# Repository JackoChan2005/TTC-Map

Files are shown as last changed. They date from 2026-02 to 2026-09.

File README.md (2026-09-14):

# TTC Map

A Toronto rail explorer and ESP32 LED display built around one transit-state API.
The web map shows Lines 1, 2, 4, 5 and 6 over OpenStreetMap, with route search,
station details, directional markers and a schematic view.

The project implements GTFS import and validation, bounded NTAS polling, estimated
train positions, a shared web/LED state model, the browser interface and firmware
for an eight-LED board revision. Contributor history is available in Git; individual
ownership and asset permissions are documented in [docs/ASSETS.md](docs/ASSETS.md).

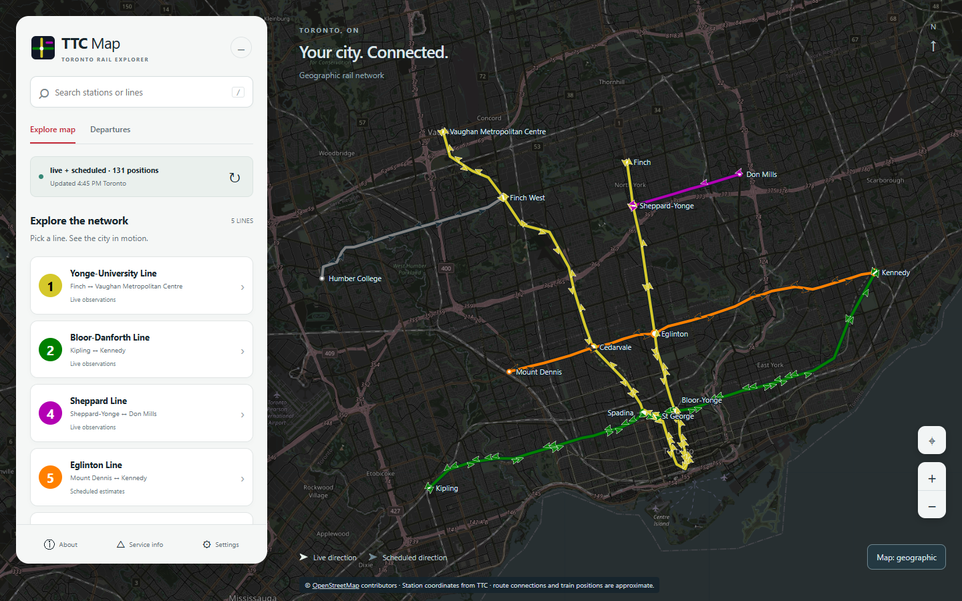
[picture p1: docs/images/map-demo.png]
TTC Map geographic explorer


The image records a real-data session on September 12, 2026; it is not a live feed.

```text
Toronto Open Data GTFS -> validated SQLite schedules/topology --+
TTC NTAS countdowns -> per-line snapshots and interpolation ----+-> map state
                                                               |-> web explorer
                                                               +-> ESP32 LED frame
```

Python/FastAPI serves the vanilla JavaScript/SVG frontend. SQLite, pandas and
HTTPX handle data; ESP-IDF/PlatformIO builds the firmware. There is no frontend
build step and no Node server.

## What the map means

- Filled arrows are NTAS-backed estimates; outlined arrows are scheduled estimates.
  Neither is GPS. Routes connect station coordinates approximately, not surveyed tracks.
- Lines 1/2/4 use NTAS when healthy. Line 5 is scheduled unless explicitly enabled
  after [coverage validation](docs/LINE_5_6.md); Line 6 is schedule-only.
- Direction follows API travel order. Unknown direction uses a neutral marker.
- Departures are scheduled, within a two-minute line-wide window capped at 200 rows.
  Service alerts, live station arrival boards and journey planning are unavailable.
- Data health does not imply normal TTC operations. Failed state requests clear
  train markers; a missing street background leaves the transit overlay usable.

## Run on Windows

Install [uv](https://docs.astral.sh/uv/getting-started/installation/), clone this
repository, then double-click `start.bat` or run it from PowerShell:

```powershell
.\start.bat
```

The launcher installs the locked dependencies and starts the server. It keeps
Python packages in `%LOCALAPPDATA%\TTC-Map\venv`, outside OneDrive. Python 3.13 is
selected by `.python-version`; uv can download it if needed. Do not repair or
reuse an old OneDrive-managed `.venv` to run this launcher.

Open <http://localhost:8000> for the map, `/search/` for timetable search, and
`/docs` or `/redoc` for the local interactive API reference. Stop with Ctrl+C.
For another port: `.\start.bat serve --port 8001`.

[Windows setup and clean-checkout verification](docs/SETUP.md) includes manual
commands, separate-checkout environments and offline rehearsal.

## macOS / Linux

Install [uv](https://docs.astral.sh/uv/getting-started/installation/), then open a
terminal in this repository and run:

```sh
./start.command
```

On macOS you can also double-click `start.command`. The launcher installs the
locked dependencies into `.venv` and starts the server. Open
<http://localhost:8000> and stop with Ctrl+C. Use
`./start.command serve --port 8001` for another port or `./start.command refresh`
for a feed check. If an extracted archive loses executable permissions, run
`bash start.command`.

Equivalent manual commands:

```sh
uv sync --locked
uv run --no-sync ttcmap serve
```

Python 3.12+ is supported by the package; the repository pins 3.13 for development.
Use one worker and a local SQLite database. Linux startup has been checked under
Ubuntu 24.04 (WSL2); macOS runtime and physical hardware validation remain separate
checks. See [setup verification](docs/SETUP.md#macos--linux).

## Commands

Run these after the platform-specific setup. On Windows, set
`$env:UV_PROJECT_ENVIRONMENT = "$env:LOCALAPPDATA\TTC-Map\venv"` first, or use
`.\start.bat refresh` for a feed check.

| Command | Purpose |
|---|---|
| `uv run --no-sync ttcmap refresh` | Check/rebuild the feed; add `--force` for a forced rebuild |
| `uv run --no-sync ttcmap build-network` | Regenerate exports from the verified cache |
| `uv run --no-sync pytest` | Backend tests |
| `uv run --no-sync ruff check src tests` | Python lint |
| `node --test tests/web/*.test.mjs` | Frontend unit tests, optional Node.js |
| `node scripts/build-schematic.mjs` | Regenerate schematic after network export |

Browser tests use a pinned optional Playwright install; see [SETUP.md](docs/SETUP.md).
There is no separate JavaScript build, type-checker or linter configured.

## API and structure

The local API reference reads `/openapi.json` and can send GET requests without
external scripts. All transit routes are below `/api/v1`:

| GET endpoint | Data |
|---|---|
| `/health`, `/gtfs/status` | Dataset and per-line source diagnostics |
| `/map-config` | Matching generation, network and schematic |
| `/network`, `/layout/{name}` | Topology or an individual layout |
| `/map-state` | Estimated positions; source and optional time selection |
| `/departures?route=1` | Scheduled departure window |
| `/led-state`, `/led-state.bin` | Board frame as JSON or packed bits |

Refresh is CLI-only. The former `POST /api/v1/gtfs/refresh` is removed so a viewer
cannot trigger an expensive rebuild. The web refresh button reloads read endpoints.

| Directory | Purpose |
|---|---|
| `src/ttcmap/` | API, GTFS pipeline, source selection and LED renderer |
| `web/` | Explorer, timetable and local API reference |
| `shared/` | Reviewed station identities and generated network/layout exports |
| `firmware/` | ESP-IDF firmware; local Wi-Fi settings are gitignored |
| `hardware/` | Integrated KiCad design and eight-LED board map |
| `tests/`, `scripts/` | Validation and schematic generation |
| `data/` | Ignored feeds, database, local validation and private asset archive |

Run from an editable repository checkout. A standalone wheel does not include the
web/shared/hardware resources and is not a supported deployment package.

## Configuration and troubleshooting

Copy `.env.example` to `.env` for optional overrides; all fields are in
`src/ttcmap/config.py`. Local paths resolve against the checkout. For OneDrive
installations that also need database isolation, configure `DATA_DIR` and `DB_PATH`
to local storage. Cloud synchronization is not multi-host database coordination.

- **Port occupied:** use another port with the launcher/CLI.
- **Transit data unavailable:** check `/api/v1/health` and refresh logs. First import,
  expired schedules or a failed upgrade can cause 503 responses.
- **Scheduled labels:** live observations may be unavailable or disabled for that line.
- **Street map unavailable:** use the schematic; OSM tiles are an external service.
- **Firmware connection:** follow [ESP32_SMOKE_TEST.md](docs/ESP32_SMOKE_TEST.md).
  The eight-LED revision does not represent a fully wired station network.

See [ARCHITECTURE.md](docs/ARCHITECTURE.md), [UI_API_AUDIT.md](docs/UI_API_AUDIT.md),
[validation results](docs/UI_VALIDATION.md) and [asset/publication status](docs/ASSETS.md).

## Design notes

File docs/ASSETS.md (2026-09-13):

# Assets and publication status

The repository has no project-wide open-source license selected by its owners.
No new reuse rights are asserted here. Contributors must confirm the intended
license and individual contribution attribution before adding a project license.

## Hardware libraries

Integrated PCB/schematic designs remain in `hardware/`. Their placed footprints
and embedded schematic symbols remain part of those designs. The separately
downloaded model files have been removed from the tracked working tree because
the included SnapMagic Design License distinguishes integrated designs from
standalone model redistribution. License notices are retained under
`hardware/My-Custom-Footprints.pretty/`.

For library editing, obtain the relevant symbols/footprints/models from the
original provider under its terms. Required part families include ESP32-DEVKIT-V1,
SN74HC595, BSS84, C0603C104K5RACTU, CL05A104KA5NNNC and JMK105BJ105KV-F.
Set KiCad's `TTC_MODEL_DIR` path variable to your local library directory, keeping
the subfolder structure shown in `hardware/sym-lib-table`. The footprint table
uses that directory as a `.pretty` library. Board viewing does not require replacing
placed footprints; missing optional models affect external library/3D operations.
Standard KiCad libraries must be installed separately.

On the original development machine, removed files were preserved under ignored
`data/private-assets/hardware/My-Custom-Footprints.pretty`. They are not licensed
for redistribution by this document. Prior Git history still contains them;
permission or a separately approved history/publication strategy remains necessary.

## UI images

The two original design-reference JPGs are preserved only in ignored local storage
pending author/provenance confirmation. The written root design document remains.
The README image is an actual TTC-Map browser capture from September 12, 2026;
its counts and source labels record that session, not current observations.

The screenshot contains OpenStreetMap imagery and visible contributor attribution.
The map uses the public OSM tile service with normal browser caching and visible
[OpenStreetMap attribution](https://www.openstreetmap.org/copyright). Transit
station/schedule data comes from Toronto Open Data, with NTAS observations where
available. Do not remove those attributions or claim that TTC endorses the project.
No downloaded font package is bundled; the UI uses available system fonts.

## Local credentials

Legacy `TTC/`, `node-api/`, `.pio`, dependency folders, environment overrides and
secrets headers are ignored. They were not deleted or published by this cleanup.
The earlier audit found a Wi-Fi literal in a local capture tree and compiled
firmware, not in the branch commits inspected. A normal branch push and a full
folder/.git archive have different exposure boundaries.

The owner must confirm whether those local files were ever shared. If exposure
occurred or is uncertain, rotate the Wi-Fi credential first and then clean shared
copies and local capture metadata. This cleanup neither rotates router credentials
nor rewrites protected tool capture refs or published Git history.

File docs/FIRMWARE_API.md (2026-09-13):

# Firmware API

The contract between the ESP32 and the server. Designed so the firmware needs no JSON parser
and a fixed-size buffer.

## The endpoint

```
GET /api/v1/led-state.bin?map=rev-a
```

| | |
|---|---|
| Response | `200 application/octet-stream`, exactly `ceil(ledCount / 8)` bytes |
| `ETag` | Content hash of the frame. Send back as `If-None-Match` to get `304` |
| `X-Led-Count` | Number of LEDs the board revision declares |
| `X-Generated-At` | ISO 8601 timestamp of the frame |
| `X-Source` | `ntas`, `schedule`, or `mixed` (sources selected per line) |

`?map=` selects a board revision; it must match `^[a-z][a-z0-9-]*$` and name a file in
`hardware/led-maps/`. Unknown names return `404`. `rev-a` is the default.

`?source=schedule` forces the schedule simulation — useful for bench testing when you want
deterministic output within the published service calendar regardless of whether NTAS is up.

## Bit layout

LED index `i` lives in **byte `i / 8`, bit `i % 8`** — LSB first within each byte.

For `rev-a` (8 LEDs, one byte), with D1 and D4 lit:

```
on          = [0, 3]
byte 0      = 0b00001001 = 0x09
             │      │└──── bit 0 → LED 0 (D1, Finch)
             │      └───── bit 3 → LED 3 (D4, St George)
             └── bit 7 → LED 7 (D8, Don Mills)
```

Reading it back out:

```c
bool led_is_on(const uint8_t *frame, int index) {
    return (frame[index / 8] >> (index % 8)) & 1;
}
```

Note this is LSB-first, while the 74HC595 shifts out MSB-first. Reverse the bits per byte
before shifting, or walk the indices with `led_is_on()` and build the shift register word
yourself — do not pass the buffer straight through.

## Suggested poll loop

1. `GET /api/v1/led-state.bin?map=rev-a` with `If-None-Match: <last etag>`.
2. `304` → nothing changed, keep the current display and skip the shift-out.
3. `200` → store the new `ETag`, latch the bytes out to the 74HC595 chain.
4. Sleep ~5s. The server refreshes realtime data every 30s, so polling faster than that only
   costs power; slower than ~30s and the board visibly lags the trains.

## Failure behaviour

| Condition | What the server does | What the firmware should do |
|---|---|---|
| NTAS feed down | Serves the schedule simulation, `X-Source: schedule` | Nothing — the frame is still valid |
| GTFS not yet built | `503` with a JSON `{message}` body | Retry with backoff; the first build takes minutes |
| Unknown `?map=` | `404` | Fix the board revision name; do not retry |
| Server unreachable | — | Hold the last frame, retry with backoff. Consider blanking after a few minutes so a frozen display is not mistaken for live data |

## Adding a board revision

Add `hardware/led-maps/<rev>.json`. No server code changes.

```json
{
  "name": "rev-b",
  "description": "Second PCB revision",
  "ledCount": 16,
  "leds": [
    { "index": 0, "designator": "D1", "station": "99992", "stationName": "Finch" }
  ]
}
```

`station` must be a station id from `shared/network.json` — `tests/test_led.py` asserts every
LED maps to a real station, so a typo fails the test suite rather than silently never lighting
up. `GET /api/v1/network` lists the ids alongside their names.

## Five-line coverage

The server includes Lines 5 and 6 in scheduled state. Line 5 can use NTAS after
coverage validation; Line 6 is scheduled only. A mixed frame has `X-Source: mixed`.
The firmware copies this header as text, so no new source enum or wire format is
required. JSON `map-state.lineSources` explains each line's source.

The existing `rev-a` byte count and LED indices do not change. Stable application
station IDs preserve the physical mapping. New-line trains at an existing mapped
interchange (for example Kennedy) can light its LED. Additional station LEDs
require a separately verified board revision; no physical assignments are guessed.

Unavailable required schedule data (including an incomplete importer migration)
returns 503 rather than a partial successful frame. On a failed browser update,
train markers are cleared; the firmware retains its existing bounded grace period.

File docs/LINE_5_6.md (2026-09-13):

# Lines 5 and 6

All five rail lines share the GTFS import, station registry, published dataset
and map-state pipeline. Public line numbers differ from feed route IDs.
Lines 5/6 have route type 0; ordinary streetcars are excluded by public identity.

Line 5 uses schedules by default. Before adding it to `NTAS_ENABLED_LINES`,
record bounded feed checks across both directions, terminals and several operating
periods. Verify payload association, changing predictions, empty queues, coverage
and cycle duration. Stop on rate limiting. A populated response alone does not
establish live provenance or reliable coverage.

The configured Line 5 gate is 90% valid platforms per direction within the poll
deadline. General live use remains unverified. Keep schedules if the gate is not
met. Line 6 is schedule-only; no live adapter is claimed.

Tests cover station identities, short turns, atomic publication, calendars,
source isolation and generation matching. See [ARCHITECTURE.md](ARCHITECTURE.md)
and [UI_API_AUDIT.md](UI_API_AUDIT.md) for current behavior.

The rev-a board retains eight mapped LEDs. New lines can activate existing
interchange LEDs; additional stations require verified wiring and a board map.

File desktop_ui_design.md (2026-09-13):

# TTC-Map Desktop UI Redesign Summary

This document outlines the design concepts, justifications, and trade-offs for a proposed "map-first" desktop interface for the TTC-Map project.

## 1. Desktop Landing View

The landing experience is designed to immediately orient the user geographically while keeping high-level system information accessible.

The original reference image is retained locally pending provenance confirmation.
See the current implementation in [README.md](README.md).

### Design Justifications
- **Map-First Geography:** Using a full-screen, dark-themed geographic base map (rather than a schematic) allows users to instantly understand where stations and live trains are located relative to actual city streets and landmarks.
- **Floating Contextual Panel:** A floating panel on the left (similar to Google Maps or Transit) keeps the map unobstructed. It provides immediate access to route search, overall system status, and quick-links to individual lines without requiring a separate page load.
- **Subtle Live Markers:** Train icons are intentionally kept small and subtle. If the map gets crowded with active trains, large icons would overlap and create visual noise.

### Trade-offs
- **Geographic vs. Schematic Clarity:** A true geographic map can make dense downtown areas (like the "U" of Line 1) feel cramped compared to a heavily distorted schematic map (like the classic TTC map). The trade-off is spatial accuracy over abstract readability.
- **Discoverability:** Floating UI panels can sometimes obscure parts of the map. While the panel is collapsible, users with smaller desktop screens might find it takes up a significant portion of their viewport compared to a traditional top navigation bar.

---

## 2. Route Details View

When a user selects a specific route (e.g., Line 1 Yonge-University), the UI shifts to a focused, progressive disclosure mode.

The original route reference is retained locally pending provenance confirmation.

### Design Justifications
- **Progressive Map Highlighting:** When a route is selected, the map zooms to fit the route's bounding box. Other subway lines are visually de-emphasized (grayed out or lowered in opacity), drawing full attention to the active route and its trains.
- **Vertical Station Timeline:** The side panel transitions from a system overview to a vertical timeline of the selected route. This makes it easy to scan the order of stations, see where trains currently are relative to the stops, and check scheduled departures when available.
- **Clear Route Branding:** The panel header takes on the official color of the selected route (Yellow for Line 1), reinforcing to the user exactly which context they are currently viewing.

### Trade-offs
- **Loss of Global Context:** By visually de-emphasizing the rest of the network, users temporarily lose system-wide situational awareness. If they are looking to plan a trip that involves a transfer to Line 2, the de-emphasized Line 2 might be slightly harder to read until they exit the route-specific view.
- **Vertical Scrolling:** Line 1 has many stations. A vertical list means users will have to scroll to see the entire route's details. An alternative would be a horizontal bottom-drawer timeline, but that would sacrifice vertical map space which is often more valuable on widescreen desktop monitors.

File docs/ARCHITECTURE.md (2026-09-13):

# Architecture

One Python service serves a rail map, scheduled departure search and ESP32 LED
frames. Node is an optional development tool for generating the schematic and
running frontend tests; it is not needed for service startup.

## Modules and contracts

| Path | Responsibility |
| --- | --- |
| `src/ttcmap/gtfs/rail_routes.py` | Select public lines 1/2/4/5/6 and validate their GTFS types |
| `src/ttcmap/gtfs/ckan.py` | Discover the ZIP resource, retain content-addressed ZIPs, verify offline cache, isolate extraction |
| `src/ttcmap/gtfs/build.py` | Validate and order rail stop times; build canonical content hashes; stage and publish tables/artifacts |
| `src/ttcmap/gtfs/network.py` | Resolve stable station identities and validate full/short-turn patterns in both directions |
| `shared/stations.json` | Reviewed application station identities, aliases and GTFS parent crosswalk |
| `src/ttcmap/gtfs/service_calendar.py` | Resolve service dates, weekday calendars, exceptions and validity |
| `src/ttcmap/gtfs/refresh.py` | Coordinate version checks, importer upgrades and publication |
| `src/ttcmap/gtfs/refresh_lock.py` | Native OS writer lock shared by CLI and server |
| `src/ttcmap/db.py` | SQLite access and a transaction-pinned Dataset context |
| `src/ttcmap/map/sources/ntas.py` | Validate and aggregate bounded HTTP polls by line and direction |
| `src/ttcmap/map/recorder.py` | Store immutable observations and carry progress floors within a generation |
| `src/ttcmap/map/sources/schedule.py` | Query dated scheduled positions and operating-service windows |
| `src/ttcmap/map/segments.py` | Generation-scoped median traversal times from explicit next-stop relationships |
| `src/ttcmap/map/interpolate.py` | Convert countdowns into estimated segment progress |
| `src/ttcmap/map/__init__.py` | Choose one source per line and assemble a consistent MapState |
| `web/js/pollMap.js` | Serialize browser polling and match state to config generation |
| `src/ttcmap/renderers/led.py` | Preserve the board's packed station-occupancy bitmask |

## Published state

`data/ttc.db` contains `SUBWAY_STOP_TIMES`, `SERVICE_DAYS`,
`SERVICE_EXCEPTIONS`, and one `active_dataset` row. The row stores topology,
layouts, generation, feed-cache identity, source version and importer revision.
Runtime never falls back to reading shared topology JSON. Shared files are
reviewable build inputs/exports; the schematic is validated before publication.

A writer builds staging tables while readers continue using the old dataset.
The final transaction swaps all tables and updates the active row and metadata.
A failed preparation or transaction leaves the previous complete dataset active.
OS locking prevents the CLI and service from colliding on staging tables. A
request pins a single SQLite read transaction and does not await HTTP while
holding it. Late polls carry their old generation and cannot be applied to a new
dataset. Segment caches are bounded and keyed by generation.

The supported deployment is one server worker on one host with local SQLite.
The OS lock also coordinates local CLI invocations. A cloud-synchronized folder
is not a supported way to share the active database across hosts.

## Source policy

`NTAS_ENABLED_LINES` defaults to `["1","2","4"]`; only 1/2/4/5 are accepted.
Line 5's 90% valid-response threshold per direction is an initial enablement gate.
Existing lines retain the provisional 50% numeric threshold, now checked per
direction. Thresholds are configuration, not provider guarantees; measure before
changing them. All platforms are included until a departure-only terminal
exclusion is verified. Line 6 is never polled by this adapter.

- `auto`: combine live and scheduled lines. `fallback` flags only an enabled
  live line needing scheduled substitution.
- `schedule`: scheduled estimates for all lines.
- `ntas`: fresh recorder data for all configured live lines, with other lines
  explicitly excluded. A missing, failed or stale enabled line returns 503.
  This mode performs no additional platform HTTP requests. No enabled lines or
  no initial snapshot also returns 503.
- Explicit `at`: use schedules; `source=ntas&at=...` returns 400. Naive timestamps
  mean Toronto local time. Prefer timestamps with explicit offsets around DST.

`lineSources` is the authoritative per-line source metadata. Top-level `source`
may be `mixed`, including when one selected line currently has no trains. A lack
of predictions during scheduled service is not proof of a suspension: the map
labels the substitute as a schedule. No public reliable Line 6 live source is
claimed. Adding GTFS-Realtime is a separate change.

## Refresh and upgrade operations

Refresh is CLI-only. The former HTTP refresh route is removed. Browser viewers
can read state and diagnostics but cannot trigger publication.

Use `uv run ttcmap refresh` to check metadata and rebuild when the feed, importer
revision or local registry/layout inputs change. `--force` rebuilds even if the
version is unchanged. The recorded metadata comes from the package used for the
download. A compatible published dataset remains usable if CKAN is offline.
An importer-only offline rebuild can use the verified cached ZIP referenced by
the active dataset. Unverified old extracted files are not an offline cache.

Existing installations need a first new-format publication; until then data
endpoints report readiness 503. Before upgrading a deployed service, back up its
SQLite database with SQLite's backup API, retain the matching application
revision, and run the rebuild before switching traffic. Restore the matching DB
and code together for rollback. Do not copy an active WAL database as a single
file or restore only JSON exports.

For new stations or layout changes:

```sh
uv run ttcmap build-network
node scripts/build-schematic.mjs
uv run ttcmap refresh --force
```

`build-network` uses the published verified ZIP and only writes shared exports.
For an explicitly extracted feed use `build-network --data-dir <directory>`.
Review `shared/stations.json` first if identity resolution fails. Unknown station
identities, unsupported patterns or missing layout coordinates reject a refresh
and leave the prior dataset active. The generator does not run at server startup.

## Validation

The test fixtures contain all five rail lines plus an excluded streetcar,
feed-specific route IDs, nonconsecutive stop sequences and dated calendars.
Tests cover mixed sources, per-line timeout isolation, snapshot generations,
calendar exceptions, midnight service, exact LED bytes, transactional failure,
reader consistency, offline upgrade, OS-lock recovery and deterministic rebuilds.
Frontend tests verify mixed labels, serialized polling and generation reloads.
Live TTC availability is not a CI dependency.

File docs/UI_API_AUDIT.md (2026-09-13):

# Frontend redesign: API capability audit

Design source: root `desktop_ui_design.md`. Original reference images are kept
locally pending provenance confirmation; they supplied visual direction, not
transit data. See `ASSETS.md`.

## Architecture and reuse

The active application is `src/ttcmap/app.py`: FastAPI routers under `/api/v1`
followed by static `web/` files. The legacy `API/` and `node-api/` directories
are not registered applications. This redesign retains vanilla ES modules,
the generation-aware map poller, network/state validation and schematic geometry.
The old SVG renderer is replaced by an interactive geographic/schematic renderer.
The two page documents share one bootstrap and stylesheet. The former separate
search client and stylesheet are removed; transit HTTP access is in `web/js/api.js`.
There are no added runtime dependencies or transit backend changes. The security
policy now permits tile images from `tile.openstreetmap.org` and an origin-only
referrer, as required by the map provider.

## UI to API mapping

All paths below are relative to `/api/v1`.

| UI feature | Endpoint and verified fields | Support and behavior |
|---|---|---|
| Overview, line cards, station/line search, transfers | `GET /map-config`: `generation`, `network.lines[]` (`id`, `number`, `routeId`, `name`, `color`, `textColor`, `stations`), `network.stations`, `network.platforms`, `layout` | Supported. Search filters published names/numbers locally; no search endpoint exists. Includes Lines 1, 2, 4, 5, 6 when published. No hardcoded transit records. |
| Geographic station map | `GET /map-config`: `network.stations[id].lat/lon`; OpenStreetMap raster tiles | Supported real street background with station coordinates projected to Web Mercator. Route connections remain approximate because the transit API has no track geometry. |
| Schematic map | `GET /map-config`: `layout` | Supported; existing schematic remains available, also used if station coordinates are missing or invalid. |
| Train markers and source labels | `GET /map-state`: `generation`, `generatedAt`, `source`, `lineSources[id].source/reason`, `trains[].line/direction/at/between/progress/stationName` | Supported as inferred positions, not GPS. Filled live markers and outlined scheduled markers; estimates can be hidden. Unknown station references are not drawn. Failed requests clear all markers. |
| Route focus and station timeline | Same network and state data | Supported. Route bounding-box fit, other lines dimmed, directional station order from the canonical direction-0 order; transfers use actual station memberships. Timeline marks trains at/approaching stations. |
| Station scheduled departures | `GET /departures?route=<number>`: `requestedAt`, `matches[].deltaSeconds`, `payload.stop_id/direction_id` joined through `network.platforms[stop_id].station/line` | Partial substitute for the design's live countdowns. Two-minute, line-wide, maximum-200-row window only; no claim of exhaustive future arrivals. Cache ages countdowns and expires past results. |
| Timetable search page | `GET /departures?route=<number>&at=<ISO8601>`: `matches[].payload`, `requestedAt` | Supported. Local datetime input is explicitly labelled with the browser time zone, sent with an offset via ISO UTC; results show Toronto/service time. Retains raw schedule record disclosure. Handles 404 as no departures, plus empty results and failures. |
| Data availability dialog | `GET /health`: `status`, `gtfs.ready`, `realtime.lines[id].source` | Supported as data diagnostics only. Never presented as good service or on-time status. |
| Pan, zoom, reset, collapse, appearance, navigation | No additional requests | Supported locally. Route/station selections use query parameters and browser history. Appearance preferences last for the session. |

Station coordinates and schematic now come from one atomic `/map-config`
response. The pixel-only equirectangular `/layout/geographic` is deliberately
not used to overlay Web Mercator tiles. The existing poller rejects
map-state/config generation mismatches. Config is reused across ten-second
state polls. Route detail departures share
one in-flight promise/cache per route for 30 seconds. Navigation tokens prevent
late search/departure responses from overwriting another selection.

## Recently introduced capabilities incorporated

Reviewed commit `5187df4` (Lines 5/6 and per-line source reliability), router
registration, every current route handler, topology generation, map-state
serialization, departure SQL/response construction, health diagnostics and the
old frontend clients. There are no extra active route handlers hidden behind
the legacy directories.

- Retains the recently added atomic `/map-config` endpoint rather than reverting
  to independently fetched network/schematic artifacts.
- Uses `/health` and the coordinates already exposed by `/map-config`.
  The refinement removes the separate geographic layout request.
- Uses expanded topology for Lines 5/6 and `map-state.lineSources`, including
  unavailable lines and scheduled fallbacks. Line 6's scheduled source is never
  called live. Line 5 remains governed by backend configuration.
- Reuses `/departures` for route details as well as the existing search page.
  The backend's current service calendar logic remains authoritative.

## Existing routes deliberately unused

| Endpoint | Reason |
|---|---|
| `GET /network` | Duplicates topology already received atomically from `/map-config`. |
| `GET /layout/geographic` | Pixel-only equirectangular layout cannot directly align to Web Mercator tiles; atomic network coordinates are the better source. |
| `GET /layout/schematic` | Matching schematic already included in `/map-config`. Other valid layout names are not assumed to exist. |
| `GET /led-state`, `GET /led-state.bin` | Hardware renderer contracts, not browser map data. |
| `GET /gtfs/status` | Subset of `/health`; no duplicate diagnostic request needed. |
| CLI `ttcmap refresh` | Publication is CLI-only; the former HTTP write route was removed. Browser refresh only reloads reads. |
| `map-state?source=ntas/schedule&at=...` variants | The main map follows backend automatic source policy. Historical time selection remains in timetable search. |

## Missing capabilities and intentional limitations

| Design feature | Missing information | Current partial support / future integration |
|---|---|---|
| Exact rail alignment / GPS positions | No served GTFS shapes or vehicle GPS coordinates | Real OSM streets and API station coordinates are supported. Routes connect stations approximately; map-state progress positions trains on those connections. Validated shapes and vehicle coordinates would improve precision. |
| Per-station live arrival countdowns/headway on cards | Public map-state serialization does not expose NTAS ETA, platform arrival queues or observation age | Two-minute scheduled departures only. A station/direction arrival endpoint should expose ETA, observation time, source and freshness. Route cards show source labels rather than fabricated minutes. |
| “All lines running normally”, disruptions, on-time status | No alerts or operational-status endpoint; health measures data readiness | Informational unavailable state plus official TTC website link. Add alerts with affected routes/stations, severity, validity and timestamps. |
| Address search and point-to-point journey planning | No geocoder, itinerary planner, walking legs or transfer-time model | Search existing stations/lines. A geocoding service and journey-planning API would be needed for those additional search modes. |
| Full station departure board | Line-wide two-minute endpoint capped at 200 rows; no pagination or longer horizon | Current timetable search preserved. Add station, direction, horizon and pagination to departure data for comprehensive boards. |
| Location centering | Browser geolocation is not connected in this iteration | No invented user location. This could be implemented as an opt-in browser permission flow using published station coordinates; it does not inherently need a transit endpoint. |
| Accounts, contact form and remote preferences pictured in reference | No authentication, profile, contact submission or preference persistence services | These decorative reference controls are not presented as working actions. About, service information and session appearance controls are functional. |

No mock/demo transit data ships in `web/`, and no static JSON is silently used
when the real API fails. Populated browser-test fixtures exist only in the
optional test runner and are explicitly identified in its code and artifacts.

## Map refinement: September 12, 2026

- Verified `map-state.trains[].direction` is 0/1, following/reversing canonical
  `line.stations`. `between` is serialized in travel order. At-station arrows
  use the next segment tangent, or incoming tangent at terminals. Missing or
  inconsistent direction produces a neutral round marker.
- Live arrows use the route colour; schedule arrows have a coloured dashed
  outline. Single-line stations have coloured rings, and transfers have segmented
  rings for connected lines. Opposing arrow glyphs sit 3.5 screen pixels to the
  travel-side of their anchor so that they remain distinguishable; the underlying
  API-derived position does not change.
- Nearby observations on the same line, direction and source share a marker;
  its tooltip reports the count. No observations or coordinates are fabricated.
- Below zoom 10.8 only interchange stations, routes and trains remain. At
  10.8–12 terminals join them; at 12–13.2 ordinary stations and eligible names
  appear. At 13.2+ labels also show line numbers. Collision detection places
  transfer labels first and uses leader lines in crowded areas. Disabling
  ordinary names never disables interchange labels. Off-screen or covered
  stations need no label.
- Marker sizes are bounded in screen pixels. Wheel zoom anchors to the pointer;
  button zoom anchors to the usable map area beside or above the panel.
- Tiles use browser image loading and normal HTTP caching for the visible
  viewport only: no proxy, prefetch, offline download or alternate transit feed.
  A tile error leaves the transit overlay working with an unavailable notice.
- Provider: [OpenStreetMap tile service](https://operations.osmfoundation.org/policies/tiles/).
  Visible attribution links to its copyright page. This is a best-effort external
  service. The URL is isolated in the map renderer; switching providers also
  requires updating CSP and attribution. Pan/zoom regression tests intercept tiles;
  one fixed-viewport integration check verifies real imagery without scanning
  the public tile service.

## Validation

See `UI_VALIDATION.md` for commands, route coverage, screenshots and actual
backend availability observed during this task.

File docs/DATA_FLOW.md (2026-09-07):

# How rail data reaches the displays

The application supports Lines 1, 2, 4, 5 Eglinton and 6 Finch West. All five
have scheduled positions. NTAS is enabled for 1/2/4 by default. Line 5 can be
enabled after coverage validation; Line 6 is scheduled only.

```text
Toronto merged GTFS ZIP                 TTC NTAS platform countdowns
         |                                         |
verified cache + isolated extraction    bounded, fair per-line polling
         |                                         |
validate schedules, calendars,          immutable per-line observations
station identities and layout           with dataset generation + time
         |                                         |
SQLite transaction publishes            reject failed, stale or
schedule + active_dataset               mismatched-generation observations
         |                                         |
         +-------------- map state ----------------+
                         |
             one selected source per line
                         |
                web map + LED bitmask
```

A refresh imports only the five public rail line numbers. Lines 5 and 6 use
GTFS route type 0; ordinary streetcars also use type 0 and are excluded. Public
line numbers and stable station IDs are independent of TTC's feed-specific IDs.
The reviewed crosswalk is `shared/stations.json`.

The published SQLite dataset contains stop times, base service calendars,
date-specific exceptions, topology and both layouts. All change in one commit.
Each map computation reads them in one transaction, so a concurrent refresh
cannot combine yesterday's topology with today's schedule. The generation hash
covers schedule/calendar content, topology, layouts and importer inputs.

The schedule source applies Toronto service dates, calendar validity and holiday
exceptions. It includes the previous service day's departures above 24:00.
Positions are departure-to-departure estimates, including dwell in the segment
span; the simulator uses local civil-clock seconds, including on DST dates.

NTAS predictions are arrival countdowns, not GPS locations or durable vehicle
identities. Polling has a shared concurrency limit and a 25-second HTTP deadline.
Completed lines remain usable when another line times out. HTTP success alone is
not sufficient: payload association and coverage are checked per direction.
A failed line loses live positions immediately; observations expire after 90
seconds. The arrival cutoff expands to cover the published segment durations.

Automatic mode chooses exactly one source for each line. `lineSources` explains
the choice and `source` is `ntas`, `schedule`, or `mixed`. A deliberately scheduled
line is not an outage. Empty predictions during scheduled operating service cause
labelled estimates, not a claim that service is actually running or suspended.
If a required schedule is unavailable, the endpoint returns 503 instead of an
apparently successful partial map.

The browser loads `/api/v1/map-config` for matching topology/layout/generation,
and reloads it when map-state generation changes. It serializes polling and
clears train markers on failed updates. The existing LED bit layout is unchanged;
new-line trains can light existing interchange LEDs, but new physical stations
need a verified board mapping. See [FIRMWARE_API.md](FIRMWARE_API.md).

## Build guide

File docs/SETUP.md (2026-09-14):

# Setup and demo rehearsal

Run from a repository checkout. Web pages, station inputs and board maps live
outside the Python package; installing a wheel alone is not supported.

## Windows

Install uv and reopen the terminal so it is on PATH. The repository selects
Python 3.13; uv installs it if necessary. Initial setup needs internet access.

```powershell
.\start.bat
```

This runs `uv sync --locked --link-mode copy` and starts the CLI using
`%LOCALAPPDATA%\TTC-Map\venv`. The environment is outside the checkout because
OneDrive can lock/reparse files in `.venv`. The launcher does not alter that old
folder. It also respects an explicit `UV_PROJECT_ENVIRONMENT` override.

Equivalent manual setup:

```powershell
$env:UV_PROJECT_ENVIRONMENT = "$env:LOCALAPPDATA\TTC-Map\venv"
uv sync --locked --link-mode copy
uv run --no-sync ttcmap serve
```

Use `start.bat serve --port 8001` for another port or `start.bat refresh` for a
feed check. `TTCMAP_NO_PAUSE=1` disables the closing prompt in scripted runs.
Do not run two checkouts against the same editable environment: assign a distinct
`UV_PROJECT_ENVIRONMENT` to each. Keep that variable set for subsequent uv test
and CLI commands. In VS Code, select the corresponding `Scripts/python.exe`.

The app defaults to loopback port 8000 and one worker. For ESP32 access on a
trusted LAN, use `serve --host 0.0.0.0` and the laptop's LAN address in the local
firmware configuration. Refresh is CLI-only; there is no HTTP write route.

The database and feed archive default to ignored `data/`. To place them outside
OneDrive too, set both `DATA_DIR` and `DB_PATH` in `.env` to a local directory and
database path before the first refresh. Never share an active SQLite database
across computers through cloud synchronization.

If the first City feed request fails, the server stays up with degraded health.
Run `start.bat refresh` when connectivity returns, then reload the site. A
successful refresh is published atomically and does not require a server restart.

## macOS / Linux

Install [uv](https://docs.astral.sh/uv/getting-started/installation/) and open a
terminal in the checkout. Initial setup needs internet; uv downloads the pinned
Python 3.13 interpreter if necessary.

```sh
./start.command
```

On macOS, double-clicking `start.command` also launches it in Terminal. The
launcher checks PATH and then `~/.local/bin/uv`, runs `uv sync --locked`, and
starts the server. It stops on installation failure and passes CLI arguments
through, for example `./start.command serve --port 8001` or
`./start.command refresh`. Use `bash start.command` if an archive extraction
did not preserve executable permissions. Stop the server with Ctrl+C.

Equivalent manual commands, run from the repository root:

```sh
uv sync --locked
uv run --no-sync ttcmap serve
```

Dependencies live in `.venv` by default. Do not reuse a Windows environment on
Linux/macOS. Set `UV_PROJECT_ENVIRONMENT` to a separate local path if the checkout
is shared across operating systems or stored in a cloud-synchronized directory;
keep it set for subsequent commands. Open <http://localhost:8000> for the map.

The default LED directory uses the tracked lowercase `hardware/led-maps` path.
Linux validation uses a fresh checkout on Ubuntu 24.04 under WSL2, on its
case-sensitive filesystem, with Python 3.13.15. macOS runtime validation has not
been performed; the launcher uses Bash syntax compatible with macOS's bundled
Bash. Neither check validates physical hardware.

Startup verification on September 13, 2026 passed locked dependency installation,
113 backend tests and Ruff. The checkout path contained spaces, and the launcher
was also invoked from another directory. HTTP checks returned 200 for `/`,
`/search/`, `/docs`, `/redoc`, `/openapi.json` and `/api/v1/health`. With an empty
database and intentionally unreachable feed service, health reported degraded
and `/api/v1/map-state` returned 503 as expected. Ctrl+C completed application
shutdown. Launcher regression tests cover default startup, argument quoting,
custom ports, installation failure and command exit-code propagation. This did
not validate a live GTFS download or NTAS service availability.

## Offline rehearsal

1. While online, run `uv run --no-sync ttcmap refresh` and check
   `/api/v1/health`: the published schedule must be ready for the presentation date.
2. Stop the server. Set `MAP_SOURCE=schedule` in `.env` or the shell, then restart.
   Markers should be outlined and labelled scheduled. This uses real published
   schedules, not a synthetic feed.
3. Disconnect external access and reload `/`, `/search/`, `/docs` and `/redoc`.
   Use the schematic if street tiles are unavailable. The API reference needs
   no external JavaScript or CSS. Try a scheduled departure search.
4. Restore automatic mode for a live demonstration. Lines 5/6 remain scheduled
   by default. Never describe schedule fallback as proof of operational service.

A compatible existing publication survives a metadata outage. An offline importer
upgrade can use the checksum-verified ZIP recorded in the dataset. Neither path
makes expired calendars valid. With no usable publication or cache, transit APIs
return unavailable states; a fresh offline clone is intentionally not populated.
For a backup of a running database use SQLite's backup API, not a raw WAL file copy.

## Tests

After the platform setup above, from the repository root:

```sh
uv run --no-sync pytest
uv run --no-sync ruff check src tests
node --test tests/web/*.test.mjs
git diff --check
```

Node is optional for service startup. Browser tests require the separately pinned
Playwright package. Install it from its own directory:

```sh
cd tests/web
npm ci
npx playwright install chromium
cd ../..
node tests/web/browser-smoke.mjs
node tests/web/map-lod-smoke.mjs
node tests/web/docs-smoke.mjs
```

On PowerShell use `npm.cmd` and `npx.cmd` if script execution policy blocks their
PowerShell wrappers. Set `TTCMAP_URL` for another server port. `CHROME_PATH` can
point to an already-installed compatible Chrome instead of downloading Chromium;
there is no machine-specific executable default. `PLAYWRIGHT_MODULE` is an optional
absolute module override for existing tool installations.

The runners resolve fixtures from the repository root and write ignored results
under `data/ui-validation`. Pan/zoom tests intercept tile images. The separate
`basemap-live.mjs` is a manual, fixed-viewport integration check; do not use public
OSM tiles for repeated automated pan/zoom scans. Transit fixtures are explicitly
test-only and never become application fallback data.

Python TestClient's `httpx2` dependency is locked in the development group to avoid
the deprecated HTTPX compatibility path. Runtime feed requests continue using HTTPX.
There is no JS build/type-check/lint command configured.

If pytest reports `Access is denied` for `%TEMP%\pytest-of-<user>` on Windows,
point `TEMP` and `TMP` at an ignored writable directory for that terminal:

```powershell
New-Item -ItemType Directory -Force data\test-temp | Out-Null
$env:TEMP = "$PWD\data\test-temp"
$env:TMP = $env:TEMP
uv run --no-sync pytest
```

## Hardware and sharing

Follow [ESP32_SMOKE_TEST.md](ESP32_SMOKE_TEST.md) for firmware. A successful compile
does not verify GPIO wiring or a physical display. Optional CAD libraries are
described in [ASSETS.md](ASSETS.md).

Share a reviewed checkout or archive of the intended commit, excluding `.git`,
local captures, `data/`, `.env`, secrets headers and build directories. An archive
of an old commit still contains its old files. Asset removals in this revision do
not erase them from prior history. Resolve the remaining ownership/history questions
in [ASSETS.md](ASSETS.md) before publishing the repository itself.

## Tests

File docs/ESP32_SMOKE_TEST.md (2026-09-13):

# ESP32 smoke test

1. Copy `firmware/include/secrets.h.example` to `firmware/include/secrets.h` and set the
   Wi-Fi profiles plus the laptop's LAN URL. The local file is ignored by Git.
2. From the repository root, start the API on the laptop with
   `uv run ttcmap serve --host 0.0.0.0`. Port `8000` is the default. The server
   must be reachable from the ESP32; do not put `localhost` in `TTC_FRAME_URL`.
3. Check the binary contract from another device on the same network:

   ```text
   GET /api/v1/led-state.bin?map=rev-a
   ```

   It returns packed bytes with `ETag`, `X-Led-Count`, `X-Generated-At`, and
   `X-Source` headers. Repeating the request with `If-None-Match` should return
   `304` when the frame is unchanged.
4. Build with `pio run --project-dir firmware`, then flash the `firmware`
   PlatformIO project and open the monitor at 115200 baud. The
   expected sequence is Wi-Fi association, an `RX frame` line, decoded LED
   indices, a 74HC595 latch line, then periodic `HTTP 304` lines.

Never commit `firmware/include/secrets.h`; it contains local credentials and the
LAN address.

The project uses a 2 MB flash layout to match the checked-in SDK configuration;
this does not measure the chip's physical capacity. Keep that setting aligned when
regenerating sdkconfig. The current rev-a consumer drives eight LEDs through two
four-bit register groups. Compilation verifies neither wiring nor Wi-Fi operation.

On Windows, PlatformIO may be installed by its editor extension without being on
PATH. Its usual command is `%USERPROFILE%\.platformio\penv\Scripts\platformio.exe`;
use the PlatformIO terminal if it is installed elsewhere.

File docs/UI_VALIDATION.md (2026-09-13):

# Validation

Latest cleanup validation: September 13, 2026, Windows, Python 3.13.15 and Node 22.
See [SETUP.md](SETUP.md) for reproducible setup and [ASSETS.md](ASSETS.md) for
the remaining ownership decisions.

## Automated checks

| Check | Result |
|---|---|
| `uv sync --locked --link-mode copy` in a fresh environment | Passed; editable project built from the lockfile |
| `python -m pytest -p no:cacheprovider --basetemp=data/review/pytest-readiness-20260913` | 108 passed without warnings |
| `python -m ruff check src tests` | Passed |
| `node --test tests/web/*.test.mjs` | 41 passed; six obsolete renderer tests were removed |
| `node tests/web/browser-smoke.mjs` | Passed on the updated app and fresh source clone |
| `node tests/web/map-lod-smoke.mjs` | Passed transfer labels, collisions, zoom detail, marker bounds and tile failure |
| `node tests/web/docs-smoke.mjs` | Passed local assets, all reference URLs, GET execution, mobile and schema failure states |
| PlatformIO build with example configuration | Passed; 896,661 bytes flash and 34,528 bytes RAM |

Python checks used a separate environment under
`%LOCALAPPDATA%/TTC-Map/readiness-venv`. Browser checks used locked Playwright
1.63.0 and installed Chrome through `CHROME_PATH`, with `TTCMAP_URL` set to the
test server. See SETUP for the default Chromium installation. Pan and zoom tests
intercept tiles; no repeated real-tile scan was performed.

## Clean-clone launch

The uncommitted working source was copied into an isolated snapshot repository,
committed there only, and cloned with `git clone --no-local` into an ignored
validation directory. This tests the changed source, not the previous remote
branch. No original Git metadata, local captures, private assets, environment,
cache or database was copied. The temporary commit did not change this branch.

The final clean-clone rehearsal used `start.bat serve --host 127.0.0.1 --port
8010` and a new environment at
`%LOCALAPPDATA%/TTC-Map/boot-verification-20260913-2`. It used the installed uv
executable and package cache; this was not a new operating-system installation.
The first startup feed request failed transiently while City metadata remained
reachable. The server stayed available with degraded health. The documented
`start.bat refresh` retry then published 109 stations and valid schedules for all
five lines without restarting the server. No transit fixture populated the
application data. The server health became `ok`; its process-local `lastRefresh`
field retained the earlier startup error even though the published dataset and
per-line health fields reflected the successful external refresh.

The clean-clone Python run initially encountered a pre-existing Windows ACL error
under `%TEMP%\pytest-of-zhouj`. Pointing `TEMP` and `TMP` at the checkout's ignored
`data/test-temp` directory produced the recorded 108-pass result. SETUP documents
that workaround.

With feed origins deliberately pointed to a refusing local port, the prepared
dataset still returned HTTP 200 with scheduled positions. An empty data directory
returned degraded health and map-state 503. These checks simulate external-service
failure; they do not claim the machine was physically disconnected. The API
reference rendered while all external browser requests were blocked.

## Browser coverage

Directly loaded `/`, `/index.html`, `/search`, `/search/`, `/search/index.html`,
`/map`, `/map/`, and route/station selections for Lines 1/2/4/5/6. Real timetable
queries for all five lines returned 200. The local API reference rendered at
`/docs`, `/redoc`, `/api/` and `/api/index.html`; `/openapi.json` remains available.

Checked navigation and back, line/station search, direction selection, scheduled
countdowns, dialogs, settings, zoom, fit, geographic/schematic mode and panel
controls. Tested 1440×900, 768×1024, 390×844 and 320×640. Browser fixtures cover
empty data, missing fields/coordinates, departure 404/503, state failure clearing
markers and tile outages. All eight interchange labels remain at wide zoom. No
unexpected console, runtime or network errors occurred in successful runs.

The final browser run used the clean-clone server and current City data. It
reported 109 stations, 119 positions at capture time, live NTAS observations for
Lines 1/2/4, scheduled estimates for Lines 5/6, and successful departure queries
for all five lines. A visible browser check confirmed the geographic basemap,
coloured routes, directional train markers, departure results and both API
reference URLs. Browser warning/error logs were empty.

The rider UI calls `/api/v1/map-config`, `/api/v1/map-state`,
`/api/v1/departures` and `/api/v1/health`. The reference can issue existing GET
endpoints. Tests confirm the removed HTTP refresh route is absent from OpenAPI and
rejects POST.

## Scope

The September 12 map integration check loaded 35 real OSM tiles in one fixed
viewport with attribution and referrers. The README screenshot comes from that
session; current counts naturally differ. It is not a data fixture.

There is no JavaScript build, type checker or linter configured. A standalone
wheel is unsupported because repository resources are required. Linux, macOS,
physical GPIO and Wi-Fi connection behavior were not tested.

The successful firmware build initially reported a 4 MB PlatformIO board default
against the checked-in 2 MB SDK layout. `board_upload.flash_size = 2MB` now aligns
that metadata. PlatformIO's builder source confirms this setting controls the
comparison. A repeat build after the one-line correction could not acquire the
user-level PlatformIO lock from the sandbox; the full compile immediately before
the correction passed. Re-run the documented build outside the sandbox before
flashing hardware.

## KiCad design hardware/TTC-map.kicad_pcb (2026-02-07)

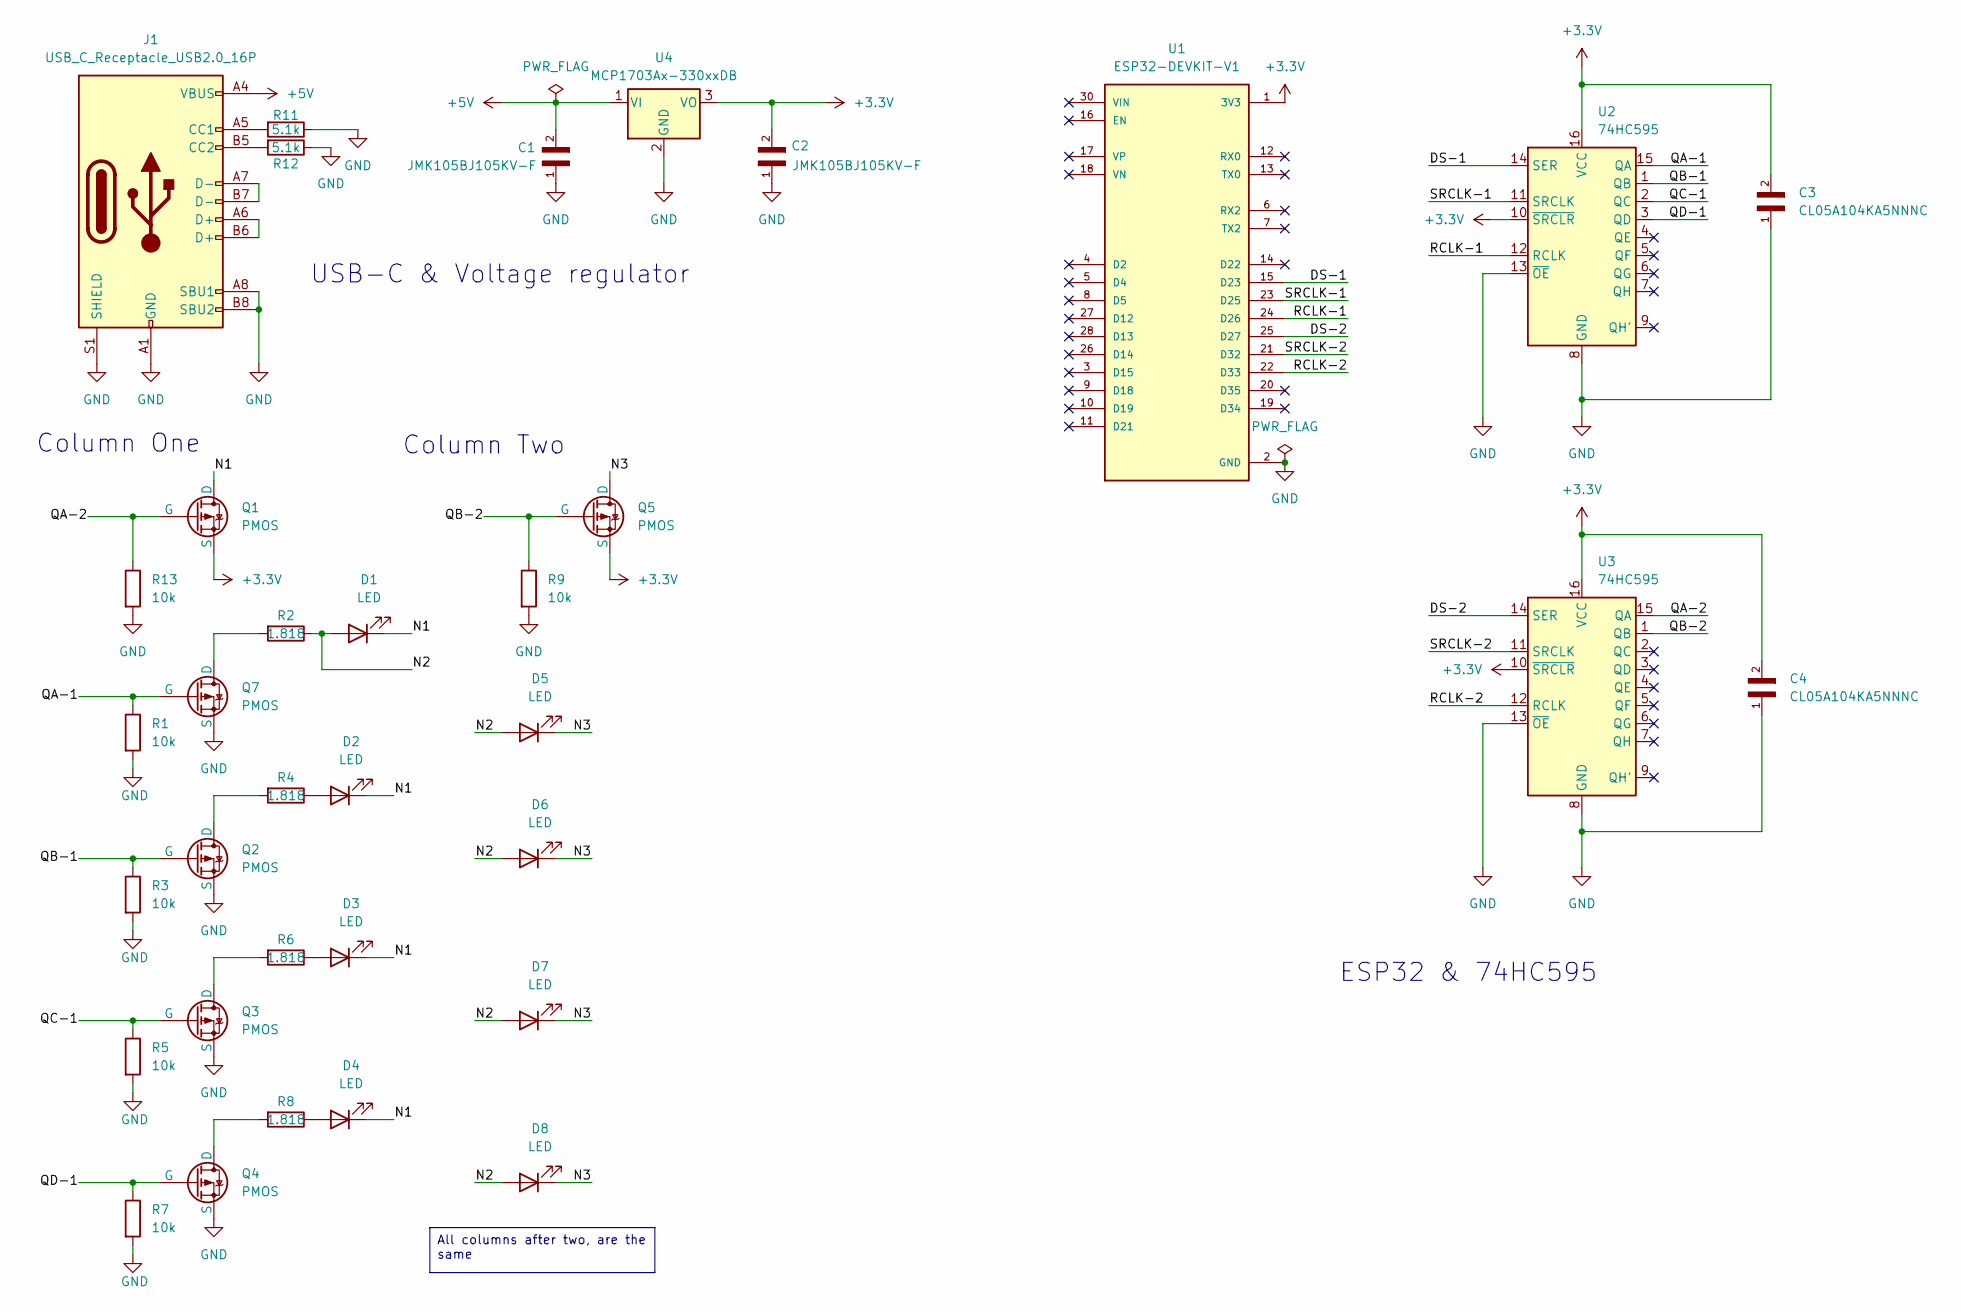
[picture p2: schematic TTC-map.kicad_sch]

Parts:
C1, C2: JMK105BJ105KV-F; CAPC1005X55N
C3, C4: CL05A104KA5NNNC; CAPC1005X55N
D1, D2, D3, D4, D5, D6, D7, D8: LED; LED_D3.0mm
J1: USB_C_Receptacle_USB2.0_16P; USB_C_Receptacle_GCT_USB4105-xx-A_16P_TopMnt_Horizontal
Q1, Q2, Q3, Q4, Q5, Q7: PMOS; SOT95P240X120-3N
R1, R3, R5, R7, R9, R13: 10k; R_0805_2012Metric
R2, R4, R6, R8: 1.818; R_0805_2012Metric
R11, R12: 5.1k; R_0805_2012Metric
U1: ESP32-DEVKIT-V1; MODULE_ESP32_DEVKIT_V1; PARTREV N/A
U2, U3: 74HC595; SOIC127P600X175-16N
U4: MCP1703Ax-330xxDB; SOT-223-3_TabPin2

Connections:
+3.3V: C2.2, C3.2, C4.2, Q1.3 (S), Q5.3 (S), U1.1 (3V3), U2.10 (~SRCLR), U2.16 (VCC), U3.10 (~SRCLR), U3.16 (VCC), U4.3 (VO)
+5V: C1.2, J1.A4 (VBUS), J1.A9 (VBUS), J1.B4 (VBUS), J1.B9 (VBUS), U4.1 (VI)
/DS-1: U1.15 (D23), U2.14 (SER)
/DS-2: U1.25 (D27), U3.14 (SER)
/N1: D1.1 (K), D2.1 (K), D3.1 (K), D4.1 (K), Q1.1 (D)
/N2: D1.2 (A), D5.2 (A), D6.2 (A), D7.2 (A), D8.2 (A), R2.1
/N3: D5.1 (K), D6.1 (K), D7.1 (K), D8.1 (K), Q5.1 (D)
/QA-1: Q7.2 (G), R1.1, U2.15 (QA)
/QA-2: Q1.2 (G), R13.1, U3.15 (QA)
/QB-1: Q2.2 (G), R3.1, U2.1 (QB)
/QB-2: Q5.2 (G), R9.1, U3.1 (QB)
/QC-1: Q3.2 (G), R5.1, U2.2 (QC)
/QD-1: Q4.2 (G), R7.1, U2.3 (QD)
/RCLK-1: U1.24 (D26), U2.12 (RCLK)
/RCLK-2: U1.22 (D33), U3.12 (RCLK)
/SRCLK-1: U1.23 (D25), U2.11 (SRCLK)
/SRCLK-2: U1.21 (D32), U3.11 (SRCLK)
GND: C1.1, C2.1, C3.1, C4.1, J1.A1 (GND), J1.A8 (SBU1), J1.A12 (GND), J1.B1 (GND), J1.B8 (SBU2), J1.B12 (GND), J1.S1 (SHIELD), Q2.3 (S), Q3.3 (S), Q4.3 (S), Q7.3 (S), R1.2, R3.2, R5.2, R7.2, R9.2, R11.1, R12.1, R13.2, U1.2 (GND), U1.29 (GND), U2.8 (GND), U2.13 (~OE), U3.8 (GND), U3.13 (~OE), U4.2 (GND)
unnamed: D2.2 (A), R4.1
unnamed: D3.2 (A), R6.1
unnamed: D4.2 (A), R8.1
unnamed: J1.A5 (CC1), R11.2
unnamed: J1.B5 (CC2), R12.2
unnamed: J1.A6 (D+), J1.B6 (D+)
unnamed: J1.A7 (D-), J1.B7 (D-)
unnamed: Q2.1 (D), R4.2
unnamed: Q3.1 (D), R6.2
unnamed: Q4.1 (D), R8.2
unnamed: Q7.1 (D), R2.2

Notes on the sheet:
USB-C & Voltage regulator
Column Two
ESP32 & 74HC595
Column One
All columns after two, are the same

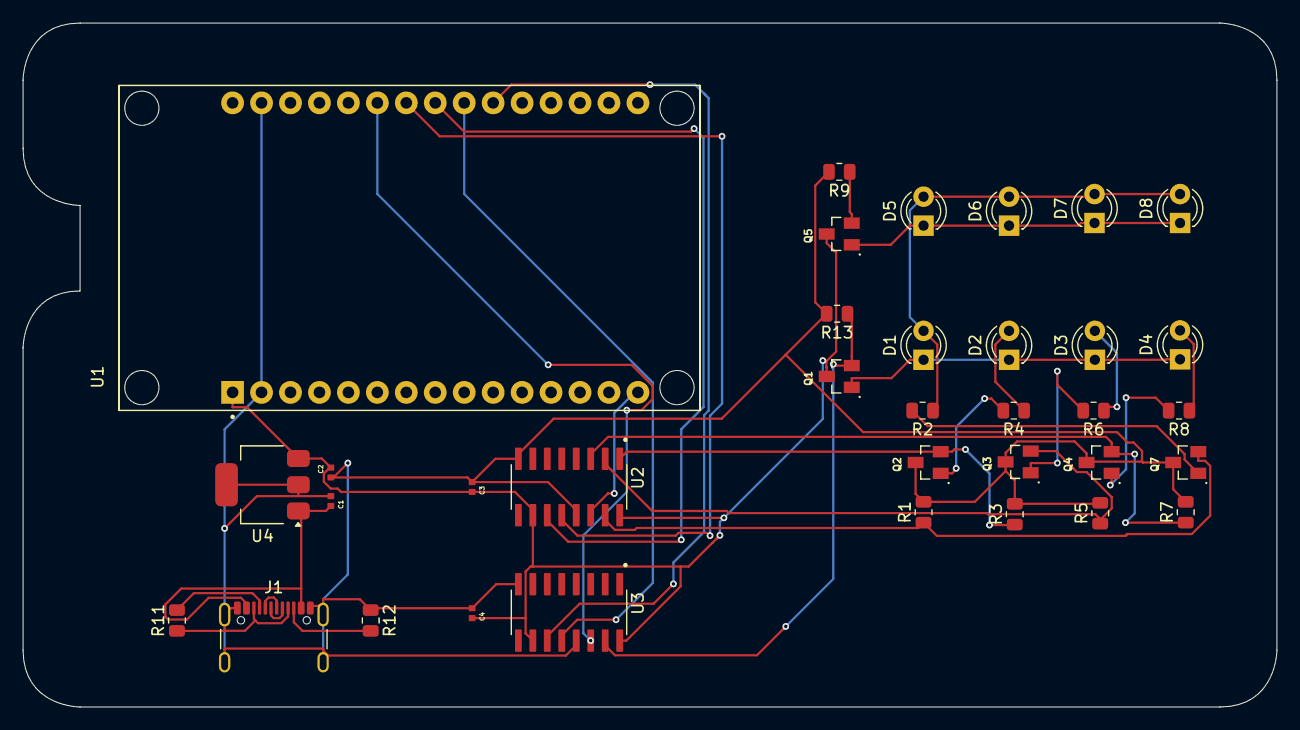
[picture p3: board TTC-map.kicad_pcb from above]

Board: 2 copper layers, 110.0 x 60.0 mm, 35 parts (0 on the bottom side), 29 nets.

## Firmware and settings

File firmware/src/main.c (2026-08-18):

#include <errno.h>
#include <inttypes.h>
#include <stdbool.h>
#include <stdint.h>
#include <stdio.h>
#include <stdlib.h>
#include <string.h>
#include <strings.h>

#include "driver/gpio.h"
#include "esp_event.h"
#include "esp_http_client.h"
#include "esp_log.h"
#include "esp_netif.h"
#include "esp_system.h"
#include "esp_wifi.h"
#include "freertos/FreeRTOS.h"
#include "freertos/event_groups.h"
#include "freertos/task.h"
#include "nvs_flash.h"

#include "board_config.h"
#include "secrets.h"

#ifndef TTC_POLL_INTERVAL_MS
#define TTC_POLL_INTERVAL_MS 5000U
#endif

#ifndef TTC_STALE_AFTER_MS
#define TTC_STALE_AFTER_MS (3U * 60U * 1000U)
#endif

#ifndef TTC_HTTP_TIMEOUT_MS
#define TTC_HTTP_TIMEOUT_MS 8000U
#endif

#ifndef TTC_VERBOSE_LED_LOG
#define TTC_VERBOSE_LED_LOG 0
#endif

#ifndef TTC_ENABLE_SHIFT_OUTPUT
#define TTC_ENABLE_SHIFT_OUTPUT 1
#endif

#ifndef TTC_WIFI_CONNECT_TIMEOUT_MS
#define TTC_WIFI_CONNECT_TIMEOUT_MS 12000U
#endif

#ifndef TTC_WIFI_RETRY_BASE_MS
#define TTC_WIFI_RETRY_BASE_MS 2000U
#endif

#ifndef TTC_WIFI_RETRY_MAX_MS
#define TTC_WIFI_RETRY_MAX_MS 30000U
#endif

#define WIFI_CONNECTED_BIT BIT0
#define WIFI_DISCONNECTED_BIT BIT1

#define TTC_MAX_ETAG_LEN 80U
#define TTC_MAX_HEADER_LEN 96U
#define TTC_MAX_SOURCE_LEN 24U
#define TTC_MAX_FRAME_BYTES ((TTC_BOARD_LED_CAPACITY + 7U) / 8U)

#if defined(TTC_WIFI_FALLBACK_SSID) != defined(TTC_WIFI_FALLBACK_PASSWORD)
#error "Define both TTC_WIFI_FALLBACK_SSID and TTC_WIFI_FALLBACK_PASSWORD"
#endif

typedef struct {
    const char *ssid;
    const char *password;
} wifi_profile_t;

static const wifi_profile_t s_wifi_profiles[] = {
    {TTC_WIFI_SSID, TTC_WIFI_PASSWORD},
#ifdef TTC_WIFI_FALLBACK_SSID
    {TTC_WIFI_FALLBACK_SSID, TTC_WIFI_FALLBACK_PASSWORD},
#endif
};

static const char *TAG = "ttc-esp32";
static EventGroupHandle_t s_wifi_events;

typedef struct {
    uint8_t body[TTC_MAX_FRAME_BYTES];
    size_t body_len;
    bool body_overflow;
    char content_type[TTC_MAX_HEADER_LEN];
    char etag[TTC_MAX_ETAG_LEN];
    char led_count_text[16];
    char generated_at[TTC_MAX_HEADER_LEN];
    char source[TTC_MAX_SOURCE_LEN];
} http_response_t;

typedef struct {
    uint8_t bytes[TTC_MAX_FRAME_BYTES];
    size_t byte_len;
    uint16_t led_count;
    uint32_t crc32;
    TickType_t last_contact;
    char etag[TTC_MAX_ETAG_LEN];
    char generated_at[TTC_MAX_HEADER_LEN];
    char source[TTC_MAX_SOURCE_LEN];
    bool valid;
    bool stale;
} led_frame_t;

static led_frame_t s_frame;

static void copy_header(char *destination, size_t destination_size, const char *value)
{
    if (!destination || destination_size == 0) {
        return;
    }
    if (!value) {
        destination[0] = '\0';
        return;
    }
    snprintf(destination, destination_size, "%s", value);
}

static esp_err_t http_event_handler(esp_http_client_event_t *event)
{
    http_response_t *response = event->user_data;
    if (!response) {
        return ESP_OK;
    }

    switch (event->event_id) {
    case HTTP_EVENT_ON_HEADER:
        if (!event->header_key || !event->header_value) {
            break;
        }
        if (strcasecmp(event->header_key, "Content-Type") == 0) {
            copy_header(response->content_type, sizeof(response->content_type), event->header_value);
        } else if (strcasecmp(event->header_key, "ETag") == 0) {
            copy_header(response->etag, sizeof(response->etag), event->header_value);
        } else if (strcasecmp(event->header_key, "X-Led-Count") == 0) {
            copy_header(response->led_count_text, sizeof(response->led_count_text), event->header_value);
        } else if (strcasecmp(event->header_key, "X-Generated-At") == 0) {
            copy_header(response->generated_at, sizeof(response->generated_at), event->header_value);
        } else if (strcasecmp(event->header_key, "X-Source") == 0) {
            copy_header(response->source, sizeof(response->source), event->header_value);
        }
        break;

    case HTTP_EVENT_ON_DATA:
        if (event->data_len <= 0) {
            break;
        }
        if (response->body_len + (size_t)event->data_len > sizeof(response->body)) {
            response->body_overflow = true;
            break;
        }
        memcpy(response->body + response->body_len, event->data, (size_t)event->data_len);
        response->body_len += (size_t)event->data_len;
        break;

    default:
        break;
    }
    return ESP_OK;
}

static uint32_t crc32_frame(const uint8_t *data, size_t length)
{
    uint32_t crc = UINT32_MAX;
    for (size_t i = 0; i < length; ++i) {
        crc ^= data[i];
        for (unsigned bit = 0; bit < 8; ++bit) {
            crc = (crc >> 1) ^ (0xEDB88320U & (-(int32_t)(crc & 1U)));
        }
    }
    return ~crc;
}

static bool parse_led_count(const char *text, uint16_t *count)
{
    if (!text || !*text || !count) {
        return false;
    }
    errno = 0;
    char *end = NULL;
    long parsed = strtol(text, &end, 10);
    if (errno != 0 || end == text || *end != '\0' || parsed <= 0 ||
        parsed > TTC_BOARD_LED_CAPACITY) {
        return false;
    }
    *count = (uint16_t)parsed;
    return true;
}

static bool response_has_required_headers(const http_response_t *response, uint16_t *led_count)
{
    if (!response || response->body_overflow || !response->content_type[0] ||
        !response->etag[0] || !response->generated_at[0] || !response->source[0]) {
        return false;
    }
    if (strncasecmp(response->content_type, "application/octet-stream", 24) != 0) {
        return false;
    }
    return parse_led_count(response->led_count_text, led_count);
}

static bool response_padding_is_zero(const uint8_t *body, size_t body_len, uint16_t led_count)
{
    if (!body || body_len == 0 || (led_count % 8U) == 0) {
        return true;
    }
    unsigned valid_bits = led_count % 8U;
    uint8_t valid_mask = (uint8_t)((1U << valid_bits) - 1U);
    return (body[body_len - 1U] & (uint8_t)~valid_mask) == 0;
}

static bool led_is_on(const uint8_t *body, size_t body_len, uint16_t index)
{
    if (!body || (size_t)(index / 8U) >= body_len) {
        return false;
    }
    return (body[index / 8U] & (uint8_t)(1U << (index % 8U))) != 0;
}

static size_t append_lit_indices(char *output, size_t output_size, const uint8_t *body,
                                 size_t body_len, uint16_t led_count)
{
    if (!output || output_size == 0) {
        return 0;
    }
    size_t used = 0;
    output[0] = '\0';
    for (uint16_t index = 0; index < led_count; ++index) {
        if (!led_is_on(body, body_len, index)) {
            continue;
        }
        int written = snprintf(output + used, output_size - used, "%s%u",
                               used ? "," : "", (unsigned)index);
        if (written < 0 || (size_t)written >= output_size - used) {
            if (output_size >= 4U) {
                snprintf(output + output_size - 4U, 4U, "...");
            }
            break;
        }
        used += (size_t)written;
    }
    if (used == 0) {
        snprintf(output, output_size, "none");
    }
    return used;
}

static void print_frame_diagnostics(const led_frame_t *frame)
{
    char hex[(TTC_MAX_FRAME_BYTES * 2U) + 1U] = {0};
    char lit_indices[(TTC_BOARD_LED_CAPACITY * 4U) + 8U] = {0};
    size_t hex_used = 0;
    for (size_t i = 0; i < frame->byte_len && hex_used + 2U < sizeof(hex); ++i) {
        hex_used += (size_t)snprintf(hex + hex_used, sizeof(hex) - hex_used, "%02x", frame->bytes[i]);
    }
    append_lit_indices(lit_indices, sizeof(lit_indices), frame->bytes, frame->byte_len,
                       frame->led_count);
    ESP_LOGI(TAG, "RX frame: hex=%s bytes=%u leds=%u source=%s crc32=%08" PRIx32,
             hex, (unsigned)frame->byte_len, (unsigned)frame->led_count, frame->source,
             frame->crc32);
    ESP_LOGI(TAG, "Decoded lit indices: %s", lit_indices);

#if TTC_VERBOSE_LED_LOG
    for (uint16_t index = 0; index < frame->led_count; ++index) {
        ESP_LOGI(TAG, "  led[%u]=%s", (unsigned)index,
                 led_is_on(frame->bytes, frame->byte_len, index) ? "ON" : "off");
    }
#endif
}

static void shift_register_write(gpio_num_t data_pin, gpio_num_t clock_pin, gpio_num_t latch_pin,
                                 uint8_t value)
{
    gpio_set_level(latch_pin, 0);
    for (int bit = 7; bit >= 0; --bit) {
        gpio_set_level(clock_pin, 0);
        gpio_set_level(data_pin, (value >> bit) & 1U);
        gpio_set_level(clock_pin, 1);
    }
    gpio_set_level(clock_pin, 0);
    gpio_set_level(latch_pin, 1);
    gpio_set_level(latch_pin, 0);
}

static void shift_output_init(void)
{
#if TTC_ENABLE_SHIFT_OUTPUT
    const gpio_config_t output_config = {
        .pin_bit_mask = (1ULL << TTC_U2_SER) | (1ULL << TTC_U2_SRCLK) | (1ULL << TTC_U2_RCLK) |
                        (1ULL << TTC_U3_SER) | (1ULL << TTC_U3_SRCLK) | (1ULL << TTC_U3_RCLK),
        .mode = GPIO_MODE_OUTPUT,
        .pull_up_en = GPIO_PULLUP_DISABLE,
        .pull_down_en = GPIO_PULLDOWN_DISABLE,
        .intr_type = GPIO_INTR_DISABLE,
    };
    ESP_ERROR_CHECK(gpio_config(&output_config));
    shift_register_write(TTC_U2_SER, TTC_U2_SRCLK, TTC_U2_RCLK, 0);
    shift_register_write(TTC_U3_SER, TTC_U3_SRCLK, TTC_U3_RCLK, 0);
#else
    ESP_LOGI(TAG, "74HC595 output disabled by TTC_ENABLE_SHIFT_OUTPUT");
#endif
}

static void shift_frame_to_board(const led_frame_t *frame)
{
#if TTC_ENABLE_SHIFT_OUTPUT
    uint8_t u2 = frame->byte_len > 0 ? frame->bytes[0] & 0x0FU : 0;
    uint8_t u3 = frame->byte_len > 0 ? (frame->bytes[0] >> 4) & 0x0FU : 0;
    shift_register_write(TTC_U2_SER, TTC_U2_SRCLK, TTC_U2_RCLK, u2);
    shift_register_write(TTC_U3_SER, TTC_U3_SRCLK, TTC_U3_RCLK, u3);
    ESP_LOGI(TAG, "74HC595 latch complete: U2=0x%02x U3=0x%02x", u2, u3);
#else
    (void)frame;
#endif
}

static void wifi_event_handler(void *arg, esp_event_base_t event_base, int32_t event_id,
                               void *event_data)
{
    (void)arg;
    if (event_base == WIFI_EVENT && event_id == WIFI_EVENT_STA_DISCONNECTED) {
        const wifi_event_sta_disconnected_t *disconnected = event_data;
        xEventGroupClearBits(s_wifi_events, WIFI_CONNECTED_BIT);
        xEventGroupSetBits(s_wifi_events, WIFI_DISCONNECTED_BIT);
        ESP_LOGW(TAG, "Wi-Fi disconnected (reason=%d)",
                 disconnected ? (int)disconnected->reason : -1);
    } else if (event_base == IP_EVENT && event_id == IP_EVENT_STA_GOT_IP) {
        xEventGroupClearBits(s_wifi_events, WIFI_DISCONNECTED_BIT);
        xEventGroupSetBits(s_wifi_events, WIFI_CONNECTED_BIT);
        ESP_LOGI(TAG, "Wi-Fi connected; local address acquired");
    }
}

static void wifi_init(void)
{
    s_wifi_events = xEventGroupCreate();
    if (!s_wifi_events) {
        ESP_LOGE(TAG, "Unable to allocate Wi-Fi event group");
        abort();
    }
    ESP_ERROR_CHECK(esp_netif_init());
    ESP_ERROR_CHECK(esp_event_loop_create_default());
    ESP_ERROR_CHECK(esp_netif_create_default_wifi_sta() ? ESP_OK : ESP_FAIL);

    wifi_init_config_t config = WIFI_INIT_CONFIG_DEFAULT();
    ESP_ERROR_CHECK(esp_wifi_init(&config));
    ESP_ERROR_CHECK(esp_wifi_set_storage(WIFI_STORAGE_RAM));
    ESP_ERROR_CHECK(esp_event_handler_register(WIFI_EVENT, ESP_EVENT_ANY_ID, &wifi_event_handler, NULL));
    ESP_ERROR_CHECK(esp_event_handler_register(IP_EVENT, IP_EVENT_STA_GOT_IP, &wifi_event_handler, NULL));
    ESP_ERROR_CHECK(esp_wifi_set_mode(WIFI_MODE_STA));
    ESP_ERROR_CHECK(esp_wifi_start());
}

static bool wifi_connect_any(void)
{
    const size_t profile_count = sizeof(s_wifi_profiles) / sizeof(s_wifi_profiles[0]);
    for (size_t profile = 0; profile < profile_count; ++profile) {
        wifi_config_t config = {0};
        snprintf((char *)config.sta.ssid, sizeof(config.sta.ssid), "%s", s_wifi_profiles[profile].ssid);
        snprintf((char *)config.sta.password, sizeof(config.sta.password), "%s",
                 s_wifi_profiles[profile].password);

        ESP_LOGI(TAG, "Trying Wi-Fi profile %u/%u", (unsigned)(profile + 1U),
                 (unsigned)profile_count);
        xEventGroupClearBits(s_wifi_events, WIFI_CONNECTED_BIT | WIFI_DISCONNECTED_BIT);
        ESP_ERROR_CHECK(esp_wifi_set_config(WIFI_IF_STA, &config));
        esp_err_t connect_result = esp_wifi_connect();
        if (connect_result != ESP_OK && connect_result != ESP_ERR_WIFI_STATE) {
            ESP_LOGW(TAG, "Wi-Fi connect request failed: %s", esp_err_to_name(connect_result));
            continue;
        }

        EventBits_t bits = xEventGroupWaitBits(
            s_wifi_events, WIFI_CONNECTED_BIT | WIFI_DISCONNECTED_BIT, pdFALSE, pdFALSE,
            pdMS_TO_TICKS(TTC_WIFI_CONNECT_TIMEOUT_MS));
        if (bits & WIFI_CONNECTED_BIT) {
            return true;
        }
        (void)esp_wifi_disconnect();
        ESP_LOGW(TAG, "Wi-Fi profile %u unavailable", (unsigned)(profile + 1U));
    }
    return false;
}

static void frame_mark_stale_if_needed(void)
{
    if (!s_frame.valid || s_frame.stale) {
        return;
    }
    TickType_t age = xTaskGetTickCount() - s_frame.last_contact;
    if (age < pdMS_TO_TICKS(TTC_STALE_AFTER_MS)) {
        return;
    }
    s_frame.stale = true;
    ESP_LOGW(TAG, "Frame is stale after %" PRIu32 " ms; blanking outputs", TTC_STALE_AFTER_MS);
    led_frame_t blank_frame = s_frame;
    memset(blank_frame.bytes, 0, sizeof(blank_frame.bytes));
    shift_frame_to_board(&blank_frame);
}

typedef enum {
    POLL_OK,
    POLL_UNCHANGED,
    POLL_RETRY,
    POLL_CONFIGURATION_ERROR,
} poll_result_t;

static poll_result_t poll_frame(void)
{
    http_response_t response = {0};
    esp_http_client_config_t config = {
        .url = TTC_FRAME_URL,
        .event_handler = http_event_handler,
        .user_data = &response,
        .timeout_ms = TTC_HTTP_TIMEOUT_MS,
        .disable_auto_redirect = true,
    };
    esp_http_client_handle_t client = esp_http_client_init(&config);
    if (!client) {
        ESP_LOGE(TAG, "HTTP client allocation failed");
        return POLL_RETRY;
    }
    ESP_ERROR_CHECK_WITHOUT_ABORT(esp_http_client_set_header(client, "Accept", "application/octet-stream"));
    if (s_frame.valid && s_frame.etag[0]) {
        ESP_ERROR_CHECK_WITHOUT_ABORT(esp_http_client_set_header(client, "If-None-Match", s_frame.etag));
    }

    esp_err_t request_result = esp_http_client_perform(client);
    if (request_result != ESP_OK) {
        ESP_LOGW(TAG, "HTTP request failed: %s", esp_err_to_name(request_result));
        esp_http_client_cleanup(client);
        return POLL_RETRY;
    }

    int status = esp_http_client_get_status_code(client);
    if (status == 304) {
        if (!s_frame.valid || strcmp(response.etag, s_frame.etag) != 0) {
            ESP_LOGW(TAG, "HTTP 304 received without a matching valid frame");
            esp_http_client_cleanup(client);
            return POLL_RETRY;
        }
        bool was_stale = s_frame.stale;
        s_frame.last_contact = xTaskGetTickCount();
        s_frame.stale = false;
        ESP_LOGI(TAG, "HTTP 304: frame unchanged; state remains valid");
        if (was_stale) {
            shift_frame_to_board(&s_frame);
        }
        esp_http_client_cleanup(client);
        return POLL_UNCHANGED;
    }

    if (status != 200) {
        ESP_LOGW(TAG, "HTTP status=%d; response rejected", status);
        esp_http_client_cleanup(client);
        return status == 404 ? POLL_CONFIGURATION_ERROR : POLL_RETRY;
    }

    uint16_t led_count = 0;
    size_t expected_bytes = 0;
    bool valid = response_has_required_headers(&response, &led_count);
    if (valid) {
        expected_bytes = (led_count + 7U) / 8U;
        valid = response.body_len == expected_bytes && response_padding_is_zero(
                    response.body, response.body_len, led_count);
    }
    if (!valid) {
        ESP_LOGW(TAG, "HTTP 200 response rejected: headers/body do not match contract");
        esp_http_client_cleanup(client);
        return POLL_RETRY;
    }

    memset(s_frame.bytes, 0, sizeof(s_frame.bytes));
    memcpy(s_frame.bytes, response.body, response.body_len);
    s_frame.byte_len = response.body_len;
    s_frame.led_count = led_count;
    s_frame.crc32 = crc32_frame(s_frame.bytes, s_frame.byte_len);
    copy_header(s_frame.etag, sizeof(s_frame.etag), response.etag);
    copy_header(s_frame.generated_at, sizeof(s_frame.generated_at), response.generated_at);
    copy_header(s_frame.source, sizeof(s_frame.source), response.source);
    s_frame.last_contact = xTaskGetTickCount();
    s_frame.valid = true;
    s_frame.stale = false;

    print_frame_diagnostics(&s_frame);
    shift_frame_to_board(&s_frame);
    esp_http_client_cleanup(client);
    return POLL_OK;
}

void app_main(void)
{
    esp_err_t nvs_result = nvs_flash_init();
    if (nvs_result == ESP_ERR_NVS_NO_FREE_PAGES || nvs_result == ESP_ERR_NVS_NEW_VERSION_FOUND) {
        ESP_ERROR_CHECK(nvs_flash_erase());
        nvs_result = nvs_flash_init();
    }
    ESP_ERROR_CHECK(nvs_result);

    shift_output_init();
    wifi_init();

    uint32_t reconnect_delay_ms = TTC_WIFI_RETRY_BASE_MS;
    uint32_t poll_failure_delay_ms = TTC_POLL_INTERVAL_MS;
    while (true) {
        EventBits_t wifi_bits = xEventGroupGetBits(s_wifi_events);
        if ((wifi_bits & WIFI_CONNECTED_BIT) == 0) {
            if (!wifi_connect_any()) {
                ESP_LOGW(TAG, "No configured Wi-Fi profile connected; retrying in %" PRIu32 " ms",
                         reconnect_delay_ms);
                vTaskDelay(pdMS_TO_TICKS(reconnect_delay_ms));
                reconnect_delay_ms = reconnect_delay_ms < TTC_WIFI_RETRY_MAX_MS / 2U
                                         ? reconnect_delay_ms * 2U
                                         : TTC_WIFI_RETRY_MAX_MS;
                frame_mark_stale_if_needed();
                continue;
            }
            reconnect_delay_ms = TTC_WIFI_RETRY_BASE_MS;
        }

        poll_result_t result = poll_frame();
        if (result == POLL_OK || result == POLL_UNCHANGED) {
            poll_failure_delay_ms = TTC_POLL_INTERVAL_MS;
        } else if (result == POLL_CONFIGURATION_ERROR) {
            poll_failure_delay_ms = 60000U;
            ESP_LOGE(TAG, "Server/map configuration error; retrying in 60 seconds");
        } else {
            ESP_LOGW(TAG, "Poll failed; retrying in %" PRIu32 " ms", poll_failure_delay_ms);
            poll_failure_delay_ms = poll_failure_delay_ms < 60000U / 2U
                                        ? poll_failure_delay_ms * 2U
                                        : 60000U;
        }
        frame_mark_stale_if_needed();
        vTaskDelay(pdMS_TO_TICKS(poll_failure_delay_ms));
    }
}

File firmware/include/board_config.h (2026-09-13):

#pragma once

// Limit remote LED counts to the physical board capacity.
#define TTC_BOARD_LED_CAPACITY 8U

#define TTC_U2_SER GPIO_NUM_23
#define TTC_U2_SRCLK GPIO_NUM_25
#define TTC_U2_RCLK GPIO_NUM_26

#define TTC_U3_SER GPIO_NUM_27
#define TTC_U3_SRCLK GPIO_NUM_32
#define TTC_U3_RCLK GPIO_NUM_33

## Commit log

2026-02-05 Added hardware designs
    [TTC-map.kicad_pcb, TTC-map.kicad_sch]
2026-02-07 Rerouted the PCB
    [TTC-map.kicad_pcb, TTC-map.kicad_sch]
2026-02-14 added wifi connection for ESP32
2026-02-16 added 3d step files to the 3d pcb viewer
2026-06-11 Document full setup: Node deps, PYTHON_BIN venv config, first sync
    README now covers the node-api flow from PR #8 (npm install, pointing
    PYTHON_BIN at the venv interpreter, npm run sync/start). Add
    DEPENDENCIES.md with the complete dependency list for new contributors.
2026-06-11 Add canonical subway topology (Phase 0 of map plan)
    build_network.py derives shared/network.json from the GTFS feed:
    ordered station lists per line (direction_id 0 travel order), official
    route colors, station coordinates, and interchange flags. Platforms are
    grouped by parent_station, with a name-based merge fallback for
    platforms missing one (Spadina on Line 1).
    network.json is the single source of truth for the upcoming map state
    engine, web renderer layout, and LED index mapping.
2026-06-11 Add map state engine, NTAS realtime source, and renderers (Phases 1-4)
    Display-agnostic pipeline behind /api/v1: sources produce TrainPosition[],
    a pure state engine turns them into MapState frames, and renderers consume
    those via mapping files.
    - scheduleSource: positions interpolated from GTFS stop_times, with the
    >24:00 late-night service window handled (verified: 71 trains on a
    weekday evening, 0 at 3:30 AM)
    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
2026-06-11 Render route search results as readable departure cards
    Replace the raw JSON dump with departure cards: line pill in official
    TTC colors, terminal direction, cleaned station name, 12-hour departure
    time with after-midnight handling, and countdown. Raw record stays
    behind a collapsible details element. All card content is built with
    textContent instead of innerHTML interpolation, the duplicated best
    match is no longer repeated in the list, the search button disables
    while a request is in flight, and the status line announces politely
    to screen readers.
2026-06-11 Update README with accurate setup instructions
    - Add prerequisites table (Python 3.12+, Node.js 18+)
    - Add Quick Setup section using python setup.py / bash Setup/Setup.sh
    - Fix cd context: npm run sync and npm start explicitly noted to run from node-api/
    - Clarify config file is env.config (not .env)
    - Add Windows PowerShell npm.cmd notes throughout
    - Add venv activation step before FastAPI alternative
    - Add API endpoints table and troubleshooting section
2026-06-11 Update instructions.txt and DEPENDENCIES.md for the new script flow
    - instructions.txt: add Quick start section for setup/start scripts,
    fix config filename (.env -> env.config, matching what server.js
    loads), list the full set of committed env vars including
    PYTHON_SYNC_*, and note that setup scripts configure PYTHON_BIN
    automatically
    - DEPENDENCIES.md: add shortcut callout for the one-click scripts,
    note PYTHON_BIN is set automatically by setup, and mention
    start.bat / start.command in the Run it section
2026-06-11 Fix fresh-clone failures found by end-to-end setup test
    - db.js: create the database directory before opening SQLite. A fresh
    clone has no API/db/ folder (git does not track empty dirs), so the
    first sync failed with SQLITE_CANTOPEN.
    - Setup.ps1 / Setup.sh: invoke pipreqs as python -m pipreqs.pipreqs;
    plain -m pipreqs fails (pipreqs is a package and cannot be directly
    executed) and silently skipped the requirements scan.
    - setup.bat: error message now points at node-api\.env.local instead
    of env.config.
2026-06-11 Rename project venv to .venv for editor auto-discovery
    VS Code Python extensions only auto-discover virtual environments
    named .venv, so a venv-named environment was invisible and the editor
    fell back to system interpreters (causing noisy pip probe errors on
    machines with pip-less Pythons like MSYS2).
    - Setup/Setup.ps1 + Setup/Setup.sh now create .venv
    - README, DEPENDENCIES.md, instructions.txt: all venv paths updated
    - New .vscode/settings.json pins the default interpreter to .venv
    - README: note to open the TTC-Map folder directly in VS Code
    Existing clones keep working: PYTHON_BIN in .env.local is an absolute
    path, and re-running setup simply creates .venv alongside the old venv
    (which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
2026-06-11 Redesign frontend: minimalist schematic main page, search at /search/
    Main page is now an octolinear schematic of the network in a minimalist
    transit-game style (original assets): 45-degree line geometry, circle/
    square/triangle markers for regular/interchange/terminal stations, and
    capsule trains riding the lines. A banner spans the top sixth of the
    viewport with a TTC LIVE SEARCH button linking to the relocated search
    page; /map/ redirects to /.
    Structure follows docs/UI_PLAN.md: pure ES modules (geometry, mapModel,
    format) hold all logic and run unmodified under node --test; render/
    svgMap.js is a thin DOM layer; the schematic layout is generated data
    (scripts/build-schematic.mjs) so oth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
2026-06-12 Add dark-mode Command Center dashboard at /command/
    React + Tailwind sub-app in dashboard/, built with Vite into
    node-api/public/command so the Express server serves it under the
    existing strict CSP (every asset self-hosted, no CDN).
    - header with TTC LIVE SEARCH action linking to /search/
    - mock octolinear network SVG (45/90-degree geometry, SMIL-pulsing
    live-train markers in line colours)
    - glassmorphism AI Operations Agent widget with interactive actions
    - fixed status dock: live train count from /api/v1/map-state with
    validated/clamped parsing and a red ALERT state on fetch failure,
    plus an accessible line legend
    Verified with headless Chrome screenshots: live-data path shows the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
2026-07-02 Bump Python dependency pins to current releases
2026-07-03 Add plain-language data flow guide
2026-08-09 Port the map state engine and Toronto time helpers
    The pure core of the map pipeline: TrainPosition[] in, MapState out, with
    no database, HTTP or clock beyond generatedAt. Sources are injected by the
    caller, which is what lets the schedule simulation, the live feed and a
    recorded snapshot be swapped without the engine or any renderer knowing.
    toronto_time.py consolidates logic that existed three times, each subtly
    different: API/src/main.py, node-api/src/routes.js and
    node-api/src/map/torontoTime.js. The GTFS >24:00 late-night window -- 01:30
    Thursday is also 25:30 Wednesday -- is preserved exactly; only the JS copy
    handled it.
    MapState keys stay camelCase because the web frontend consumes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
    [test_state.py, test_toronto_time.py]
2026-08-09 Port the schedule, NTAS and snapshot sources
    Three interchangeable producers of TrainPosition[], plus the source
    selection from node-api/src/map/index.js: auto reads the realtime snapshot
    and falls back to the schedule the moment it is failed, missing or stale,
    so stale realtime positions are never shown.
    ntas.py replaces the hand-rolled concurrency lanes with an asyncio
    semaphore over a shared keep-alive client. The "fewer than half the
    platforms responded means unavailable" rule is kept -- a partial feed would
    silently blank out sections of the map.
    recorder.py holds the snapshot in memory rather than in a SQLite row. It
    was only ever persisted because `npm run sync` ran as a separate pr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
    [test_ntas.py, test_recorder.py, test_snapshot.py]
2026-08-09 Port the LED renderer and add a raw bitmask for the ESP32
    Same packing as node-api/src/map/renderers/ledRenderer.js -- LED index i in
    byte i/8 at bit i%8, LSB first -- since that is the contract the PCB is
    designed against. A board revision stays a mapping file in
    hardware/led-maps/, so adding a display means adding a file, not code.
    Adds pack_bits and an ETag helper for the new /led-state.bin endpoint: the
    firmware gets a fixed-size buffer with no JSON parser, and can skip frames
    that have not changed.
    The JS renderer had no tests. These cover the bit layout directly, and
    assert every LED in rev-a maps to a station that exists in network.json --
    a silkscreen typo would otherwise just neve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
    [test_led.py]
2026-08-09 Serve the full /api/v1 surface from FastAPI
    One app replaces the Express server and the separate FastAPI app. Startup
    runs the GTFS check and the NTAS recorder as background tasks, so the
    server answers requests immediately -- including during the first-run
    rebuild, when it serves whatever data it has.
    Endpoint changes from the Express surface:
    /api/route-search -> /api/v1/departures
    /api/sync/run -> POST /api/v1/gtfs/refresh
    /api/sync/status -> /api/v1/gtfs/status
    /led-state.bin new, raw bitmask for the firmware
    Dropped: /api/records and /api/records/:key, along with the synced_records
    table they served -- a JSON copy of SUBWAY_STOP_TIMES rewritten in full on
    every re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
2026-08-09 Move the frontend to web/ and point it at /api/v1
    The static files no longer live inside a Node package, so they move out of
    node-api/public/ to a top-level web/ that FastAPI mounts.
    Only one line of content changes: app.js called /api/route-search, which is
    now /api/v1/departures. map/map.js already used /api/v1 and is untouched.
2026-08-09 Remove the Node API and the old Python API
    Everything both served is now answered by src/ttcmap. Deleting them removes
    the language boundary that forced the Node server to spawn Python as a
    subprocess -- the root cause of the PYTHON_BIN / .env.local / setup-script
    chain removed in the next commit.
    Gone with node-api/: the Express server and routes, the sync job and its
    CKAN client, the map pipeline (ported verbatim in the preceding commits),
    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
2026-08-09 Rename TTC/ to firmware/ and Hardware/ to hardware/
    TTC/ inside a repo called TTC-Map said nothing about what it held; it is
    the ESP32 firmware. Hardware/ is lowercased to match every other top-level
    directory.
    Pure renames, no content changes. The KiCad project references its
    footprint and symbol libraries through ${KIPRJMOD}, so nothing inside the
    project files needs editing.
    [TTC-map.kicad_pcb, TTC-map.kicad_sch]
2026-08-09 Rewrite the docs for the single-service layout
    README.md, DEPENDENCIES.md and instructions.txt had drifted into three
    overlapping setup guides, most of it describing the PYTHON_BIN and
    .env.local dance that no longer exists. They collapse into one README:
    prerequisites, one command, the endpoint table, troubleshooting.
    MAP_PLAN.md becomes ARCHITECTURE.md. It was written as a phase tracker with
    every phase marked done, so it now describes how the pieces fit rather than
    the order they were built in. The contracts it defined are unchanged.
    FIRMWARE_API.md is new and is the point of the refactor: the exact contract
    the ESP32 is written against. Byte layout and bit order for /led-state.bin,
    the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
2026-08-10 Add the countdown-to-position converter
    Turns an NTAS ETA into a position on its segment, and ages it as the snapshot
    gets older:
    remaining = eta_s - elapsed_since_poll
    progress = 1 - remaining / span while 0 < remaining < span
    Anchoring to the arrival rather than integrating from a previous position is
    deliberate. Dead reckoning was the obvious alternative and does not work here:
    it needs to recognise the same train across two polls, and NTAS carries no train
    ids, so it would need an association heuristic that is fragile exactly where it
    matters. A countdown is a fact about a place and a time, so each poll can
    rebuild from scratch with no identity at all — and the error co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
    [test_interpolate.py]
2026-08-15 Add ESP32 binary LED pipeline
2026-09-14 Fix and verify Linux/macOS startup launcher
    [test_launcher.py]
